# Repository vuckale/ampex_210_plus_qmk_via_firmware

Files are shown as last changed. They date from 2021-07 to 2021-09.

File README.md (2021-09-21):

# <b> Ampex 210 plus </b> - 80s keyboard gets QMK and VIA support 

ampex-210-plus-qmk-via-firmware

<!--*A short description of the keyboard/project*-->
<b> Ampex 210 plus </b> is a terminal keyboard, manufactured for [Ampex](https://en.wikipedia.org/wiki/Ampex) by [Hi-Tek](https://deskthority.net/wiki/Hi-Tek_Corporation). It uses [Hi-Tek Series 725](https://deskthority.net/wiki/Hi-Tek_Series_725) AKA <b> space invader</b> switches. This particular models uses tow eyed, linear switches.

I removed original MCU (40 pin 8-bit Mitsubishi M5L8048-186P) and replaced it with Teensy++ 2.0 (AT90USB1286). With some rewiring Teensy++ 2.0 was almost pin to pin compatible with existing pads. Flashing QMK firmware onto Teensy makes this keyboard programmable and replaces existing 4-pin RJ connector with USB mini.

# Features

* USB mini B
* 4 programmable layers
* 16 macro keys
* bootmagic on esc key
* speaker
* VIA

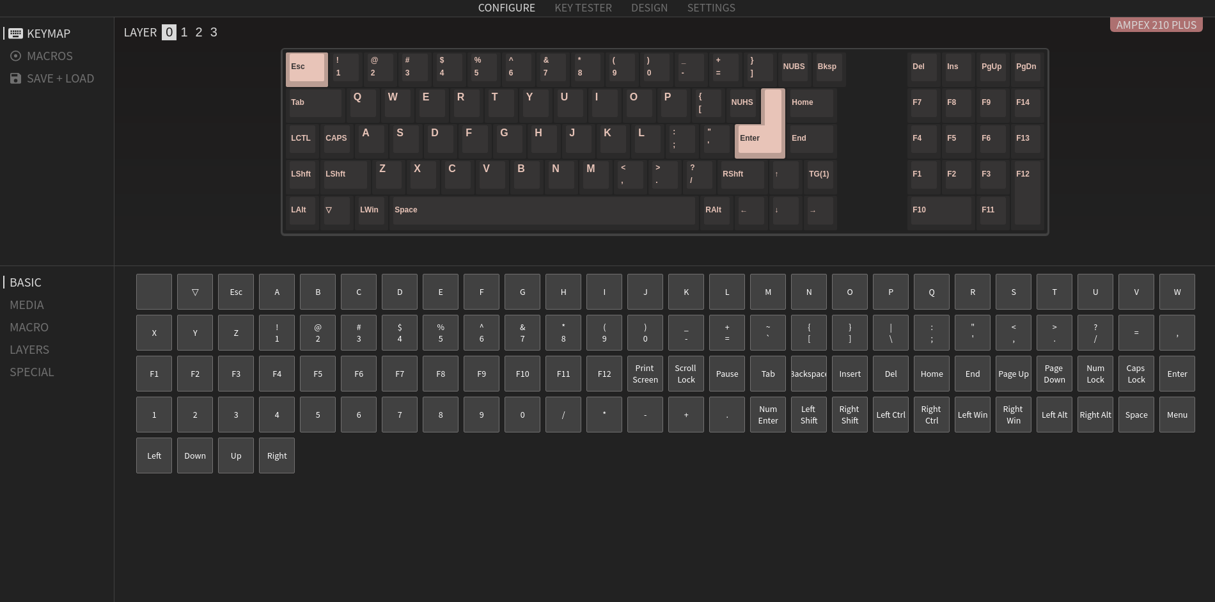
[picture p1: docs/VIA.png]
VIA


# Wiring
&ast; Pins <b>D5</b> and <b>D6</b> were causing some permanent shorting when using this keyboard over USB 3.0. As marked bellow, those two pins had to be jumped to pins <b>F6</b> and <b>F7</b>. Every other pin is as marked, and Teensy only has to be shifted one pin to left in the exact orientation as pictured. Pins on PCB marked with red are unused.
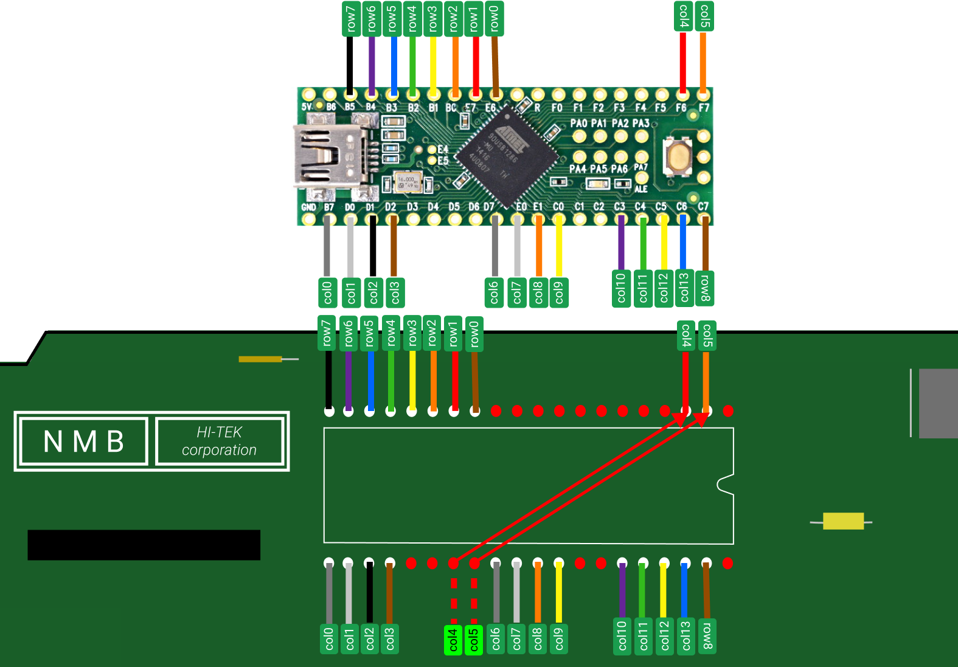
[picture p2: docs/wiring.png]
matrix-wiring


&ast; The pinout above does not include two <b> shift </b> and <b> ctrl </b> keys. Due to design (or some other reason), this keyboard had both shift keys act as single key. Ctrl key was routed through some other components that I didn't want to desolder. In this firmware I rewired those keys into separate rows and columns only because that was the easiest and cleanest way to reach controller pins i.e. you can rewire it to some other free row-column combinations. 
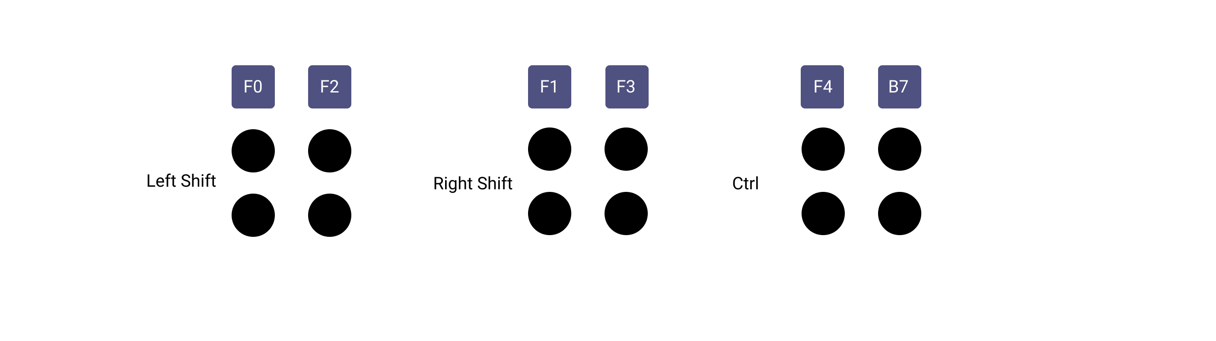
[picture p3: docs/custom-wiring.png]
right-left-shift-wiring


&ast; 6 trace connectors coming from 2 shift keys and ctrl key have to be cut. Not doing so will cause some delay in input. The trace connectors that have to be cut are marked on the picture bellow with small red circles.
pcb-back-wiring

&ast; I have soldered only the pins that I am using in this firmware. To achieve this I have cut pins that are not used. Soldering all the pins might produce a short or some other type of interference. 
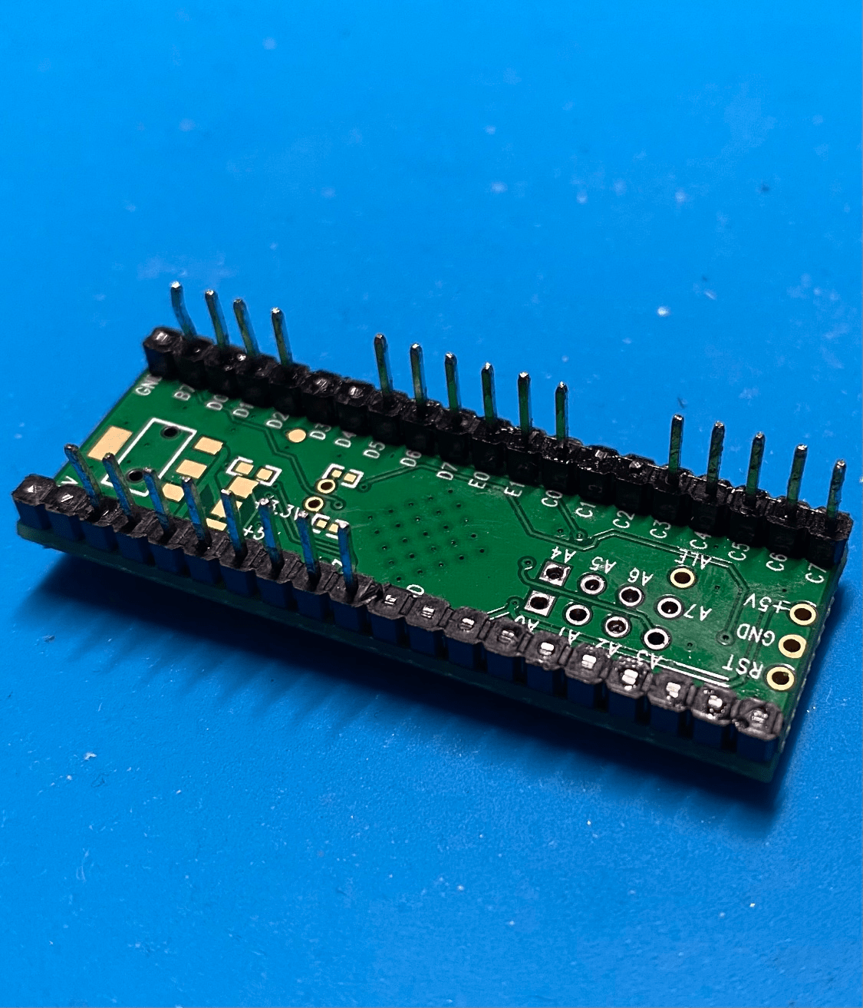
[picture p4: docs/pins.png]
pins


# Key Matrix
&ast; Rows and colums colored in green are extra rows and columns I mentioned in Wiring section.
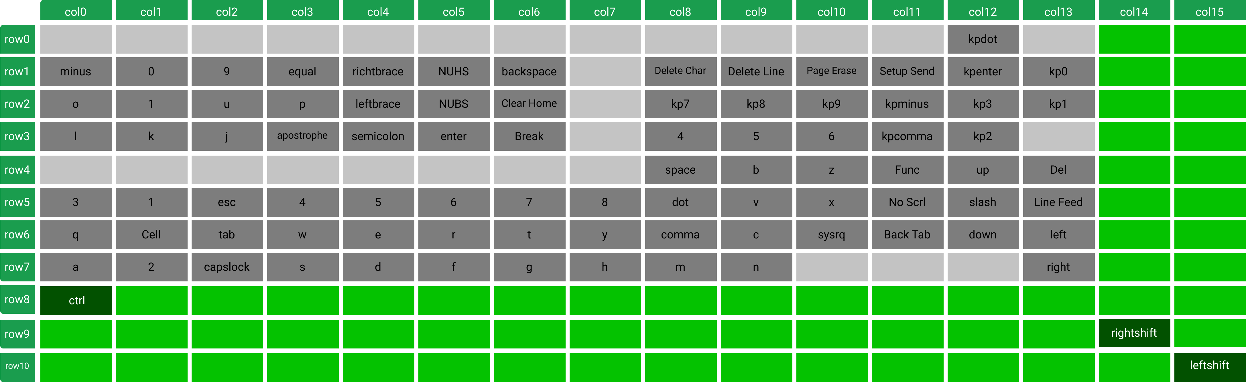
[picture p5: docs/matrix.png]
key-matrix

# Speaker Wiring
&ast; This PCB has a marking <b>SP1</b> for speaker. Two pins comming out on the back of the PCB have to be jumped to pins marked bellow.
<p align="center">
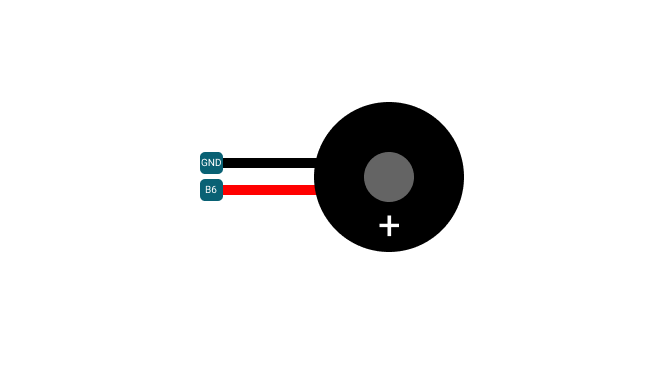
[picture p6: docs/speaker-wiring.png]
  
</p>

# 3D-Print ready stabilizers
&ast; If you happen to break stabilizers you can get the files to 3D-print them [here](https://github.com/vuckale/ampex-210-plus-qmk-via-firmware/blob/main/stabilizers_stl/) 
stabilizers

# More pictures
&ast; Flat
flat

&ast; 11° angle


&ast; Logo
closeup

&ast; [Operation Manual](https://archive.org/details/bitsavers_ampextermiperatingManualApr84_11028631/mode/2up)

<p align="center">
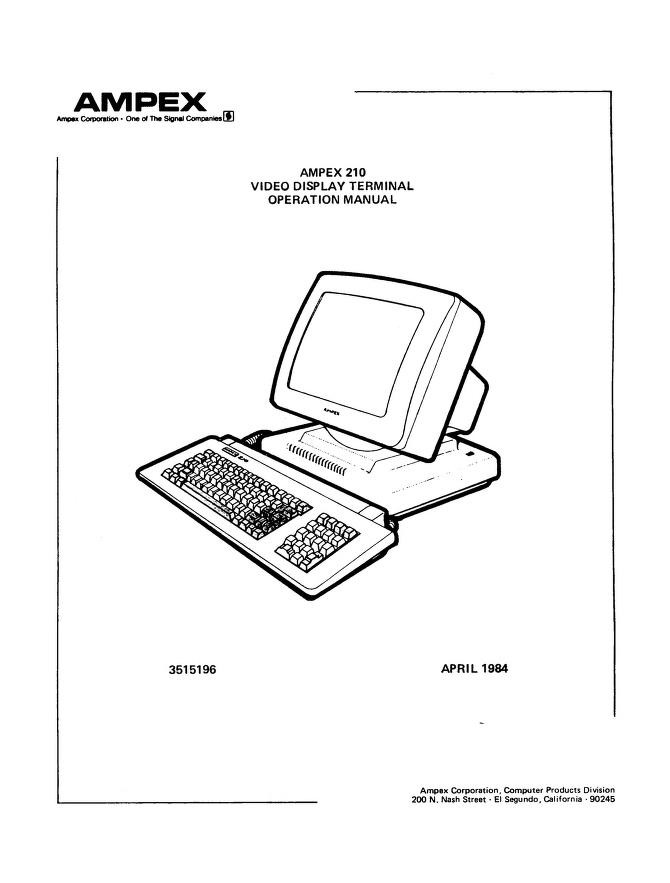
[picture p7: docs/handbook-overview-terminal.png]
  
</p>
<!--* Keyboard Maintainer: [vuckale](https://github.com/yourusername)
* Hardware Supported: Teensy++ 2.0 USB based microcontroller
* Hardware Availability: *Links to where you can find this hardware*-->

<!--Make example for this keyboard (after setting up your build environment):

    make compaq-mx-11800:default

Flashing example for this keyboard:i

    make compaq-mx-11800:default:flash

or for VIA support:
    
    make compaq-mx-11800:via:flash

<!--See the [build environment setup](https://docs.qmk.fm/#/getting_started_build_tools) and the [make instructions](https://docs.qmk.fm/#/getting_started_make_guide) for more information. Brand new to QMK? Start with our [Complete Newbs Guide](https://docs.qmk.fm/#/newbs).-->

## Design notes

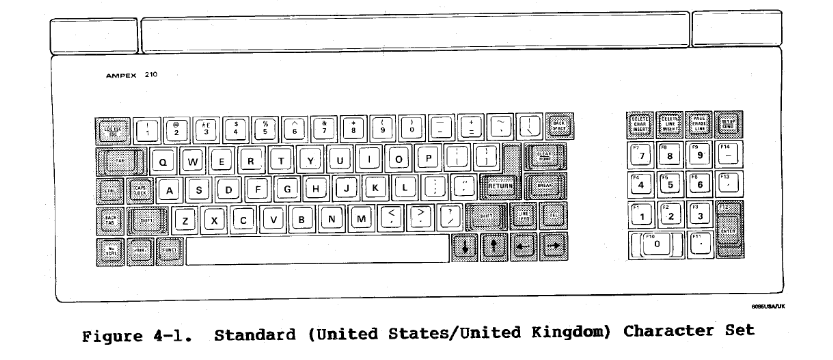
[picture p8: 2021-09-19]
docs/handbook-overview-keyboard.png

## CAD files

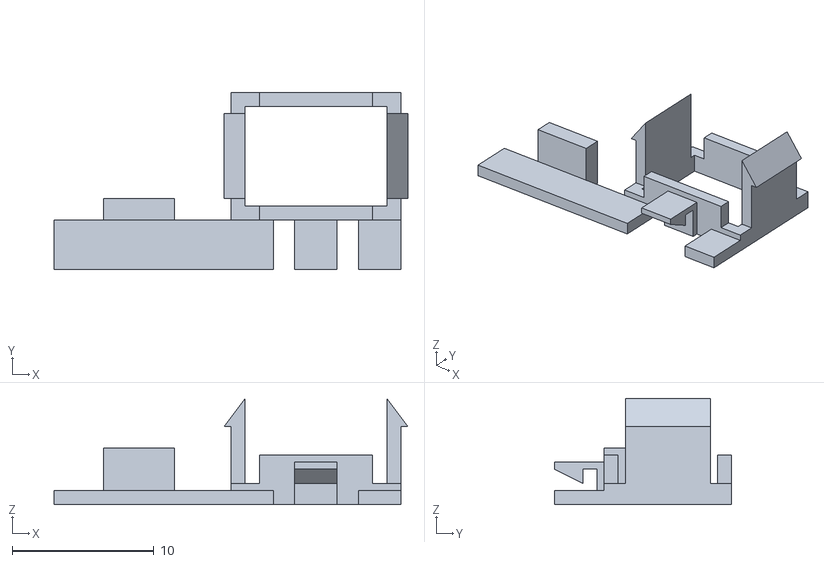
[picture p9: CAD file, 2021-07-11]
stabilizers_stl/right.stl
25.0 x 12.5 x 7.50

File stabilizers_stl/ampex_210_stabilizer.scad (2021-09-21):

/*
Copyright 2021 vuckale

This program is free software: you can redistribute it and/or modify
it under the terms of the GNU General Public License as published by
the Free Software Foundation, either version 2 of the License, or
(at your option) any later version.

This program is distributed in the hope that it will be useful,
but WITHOUT ANY WARRANTY; without even the implied warranty of
MERCHANTABILITY or FITNESS FOR A PARTICULAR PURPOSE.  See the
GNU General Public License for more details.

You should have received a copy of the GNU General Public License
along with this program.  If not, see <http://www.gnu.org/licenses/>.
*/
cube([3,1,3.5]);

translate([9,0,0]) cube([15.5,1,3.5]);

translate([0,0,-1]) cube([12,1.5,1]);

translate([2,0,-1]) cube([8,3.5,1]);

translate([4.5,2.5,0]) cube([3,0.5,3.5]);


module prism(l, w, h) {
    polyhedron(
           points=[[0,0,0], [l,0,0], [l,w,0], [0,w,0], [0,w,h], [l,w,h]],
           faces=[[0,1,2,3],[5,4,3,2],[0,4,5,1],[0,3,4],[5,2,1]]
    );
    z = 0.08;
    separation = 2;
    border = .2;
}

translate([7.5,2.5,3.5]) rotate([90,180,00]) prism(3, 2, 1);

translate([4.5,0,0]) cube([3,3,0.5]);

translate([0,0,-9]) cube([1,1.5,8]);

translate([0,0,-7.5]) cube([1,6,6]);

translate([1,7.5,-1.5]) rotate([180,90,0]) prism(6, 2, 1.5);

translate([11,0,-9]) cube([1,1.5,8]);

translate([11,0,-7.5]) cube([1,6,6]);

translate([12.5,5.5,-1.5]) rotate([0,90,90]) prism(6, 1.5, 2);

translate([0,0,-9]) cube([12,1.5,1]);

translate([2,0,-9]) cube([8,3.5,1]);

translate([16,0,-1.5]) cube([5,4,1.5]);

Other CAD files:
stabilizers_stl/left.stl

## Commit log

2021-07-11 add stabilizers .stl files
    [ampex_210_stabilizer.scad, left.stl, right.stl]
2021-09-10 add qmk firmware config files for teensy++ 2.0
2021-09-10 add scaled stabilizers .stl files
    [right_104.stl, right_106.stl, right_107.stl]
2021-09-15 add .gif for stabilizer .stl
